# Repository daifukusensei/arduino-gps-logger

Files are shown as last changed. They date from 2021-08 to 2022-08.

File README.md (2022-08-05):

# Project Pluto: Arduino GPS w/ microSD logging and Bluetooth
This is Project Pluto: an Arduino-based battery-powered GPS data-logger with customizable settings and Bluetooth pairing to mobile phone or compatible DSLR.

The finished product is self-contained on a printed PCB in a 3D-printed enclosure, with majority of components plugged into headers to aid in possible future upgrades and enable repurposing of components.

<p align="center">
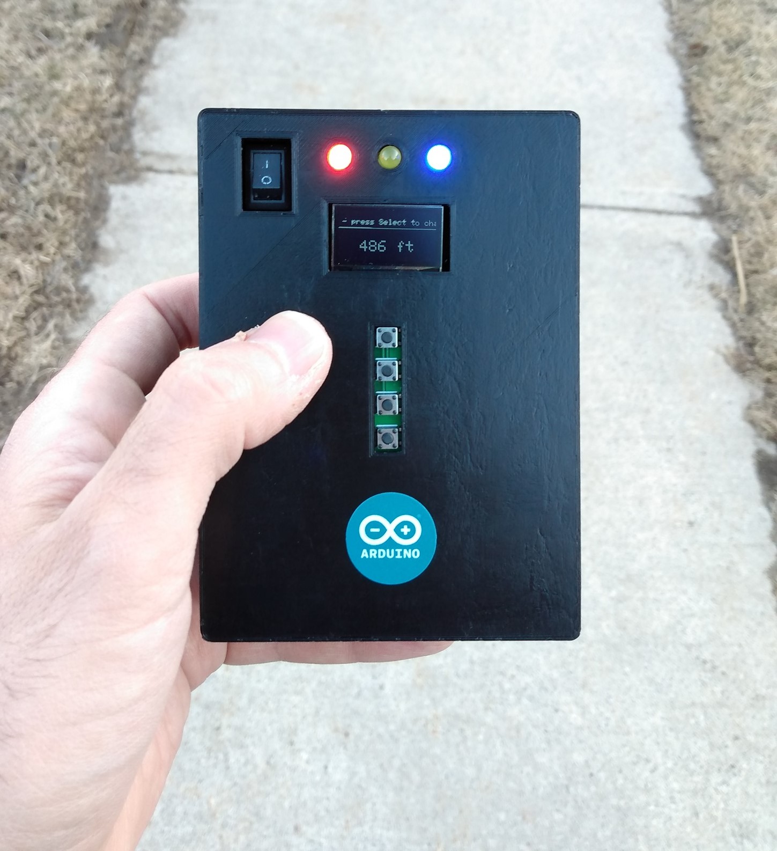
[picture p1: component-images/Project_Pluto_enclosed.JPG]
  
</p>

## Why?
I'm an active travel photographer, and use various hardware & software-based solutions to geo-tag my images on the fly. With no prior knowledge of Arduino development, CAD, electronics or circuit design, I wanted to see if I was able to build a portable geo-tagging solution to meet my own needs. And I did it. Kind of (see [Disclaimer](#Disclaimer)).

On a whim and for no particular reason, I've named it Project Pluto.

## Features
- Display of various parameters in real-time (co-ordinates, date & time, speed, altitude, heading and satellite count), with the ability to change measurement units where applicable (ie. feet or meters)
- Logging of co-ordinates to microSD card
- Bluetooth pairing with mobile phone or NMEA 0183-compatible DSLR (see [Specifications and Requirements](#Specifications-and-Requirements))
- LEDs to indicate satellite and Bluetooth fix, and microSD card activity
- Individual features (logging, Bluetooth, LEDs) may be toggled on or off, with settings retained across power-cycles
- Long-pressing of individual buttons to quickly toggle key settings (logging, Bluetooth or LED state)

## Repository Contents
- [C++ source code](./arduino-gps-logger.ino) for uploading to an Arduino or compatible clone
- [EasyEDA project](./PCB) for modifying the PCB schematic
- [Fritzing circuit diagram](./Fritzing-circuit-diagram.fzz)
- [Gerber file](./PCB) for printing a PCB
- [STL files](./STL) for 3D-printing an enclosure

## Parts List
| Quantity | Description | Note |
| --- | --- | --- |
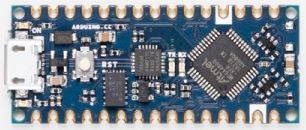
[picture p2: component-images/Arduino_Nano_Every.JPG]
Image of Arduino Nano Every
| 1 | Arduino Nano Every w/ soldered straight male headers | A genuine Arduino Nano Every is required as clones do not use the required ATMega4809 processor<br/> |
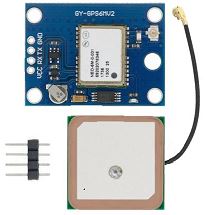
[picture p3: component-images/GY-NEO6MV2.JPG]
Image of GY-NEO6MV2
| 1 | u-blox NEO-6M GPS module w/ external antenna and built-in EEPROM, and soldered straight male header | Part GY-NEO6MV2:<br/> |
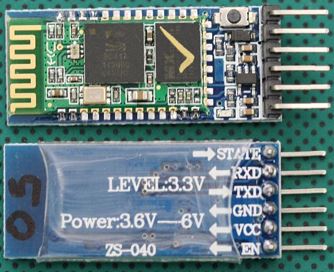
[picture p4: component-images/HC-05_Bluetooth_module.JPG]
Image of HC-05 Bluetooth module
| 1 | HC-05 Bluetooth module on ZS-040 baseboard w/ soldered right-angle male header | Enable and State pins need to be connected for programming<br/> |
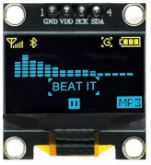
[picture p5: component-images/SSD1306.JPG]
Image of SSD1306 0.96" 128x64 I2C OLED
| 1 | SSD1306 0.96" 128x64 I2C OLED display w/ soldered straight male header | Of the following form-factor:<br/> |
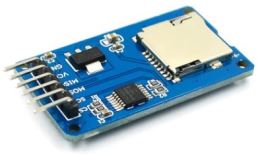
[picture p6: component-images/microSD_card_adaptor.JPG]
Image of SPI microSD card adaptor
| 1 | SPI microSD card adaptor w/ soldered right-angle male header | Of the following form-factor:<br/> |
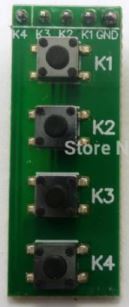
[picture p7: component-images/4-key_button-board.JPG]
Image of 4-key button-board module
| 1 | 4-key button-board module w/ soldered straight male header | |
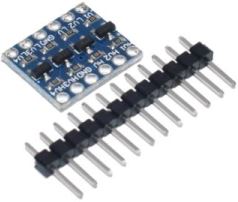
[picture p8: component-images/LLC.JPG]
Image of LLC
| 1 | 4-channel 3.3V/5V bi-directional logic-level-converter (LLC) w/ soldered straight male headers | Of the following form-factor:<br/> |
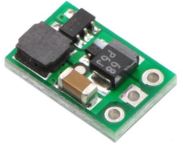
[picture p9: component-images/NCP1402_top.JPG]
Image of NCP1402 top
| 1 | Pololu 5V step-up voltage regulator w/ soldered straight male header | Part NCP1402:<br/>Image of NCP1402 bottom |
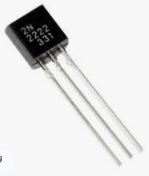
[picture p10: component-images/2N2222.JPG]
Image of 2N2222
| 1 | 2N2222 NPN transistor | For turning on and off the HC-05 Bluetooth module<br/> |
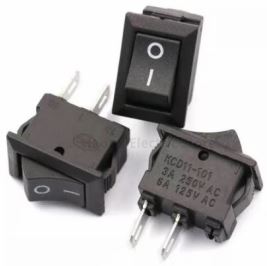
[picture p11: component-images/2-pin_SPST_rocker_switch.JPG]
Image of 2-pin SPST rocker switch
| 1 | 2-pin SPST rocker switch | 15mm\*10mm, in the following form-factor:<br/> |
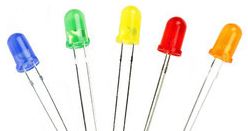
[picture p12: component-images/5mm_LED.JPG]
Image of 5mm LED
| 3 | 5mm LED | Can be a standard 'dome' shape, resulting in slight protusion when in enclosure; or flat-top, which will be flush with enclosure.<br/>Each should ideally be of a different color to represent their distinct use; I use red for satellite fix, yellow for logging, and blue for Bluetooth fix<br/> |
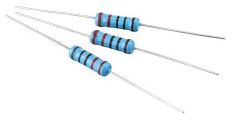
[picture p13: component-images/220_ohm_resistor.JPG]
Image of 220Ω resistor
| 3 | 220Ω resistor |  |
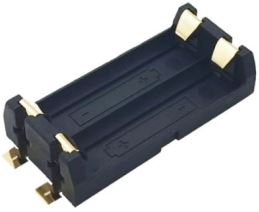
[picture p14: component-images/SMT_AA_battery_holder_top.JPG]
Image of SMT AA battery holder top
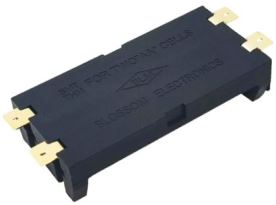
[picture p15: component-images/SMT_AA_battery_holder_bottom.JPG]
Image of SMT AA battery holder bottom
| 1 | SMT AA battery holder | Approximately 59mm\*29mm (from Blossom Electronics, or Keystone part 1022):<br/> |
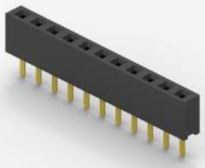
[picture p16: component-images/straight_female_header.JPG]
Image of straight female header
| 1 | 3-pin 2.54mm-pitch straight female header | Source rows of these in bulk, from which the required size can be cut:<br/> | 
| 2 | 15-pin 2.54mm-pitch straight female header | Source rows of these in bulk, from which the required size can be cut:<br/>Image of straight female header |
| 2 | 4-pin 2.54mm-pitch straight female header | Source rows of these in bulk, from which the required size can be cut:<br/>Image of straight female header |
| 2 | 6-pin 2.54mm-pitch right-angle female header | Source rows of these in bulk, from which the required size can be cut:<br/>Image of right-angle female header |
| 2 | 6-pin 2.54mm-pitch straight female header | Source rows of these in bulk, from which the required size can be cut:<br/>Image of straight female header |
| 3 | 2-pin 2.54mm-pitch straight female header | Source rows of these in bulk, from which the required size can be cut:<br/>Image of straight female header |
| 4 | 6mm M2 screw | Used in retaining u-blox NEO-6M GPS module and SSD1306 0.96" 128x64 I2C OLED display on printed PCB.<br/>Source a single 'M2 Male-Female Spacer Standoff Screw Nut' kit that contains all required screw/spacer/standoff parts from this list:<br/>Image of 6mm screw |
| 2 | 8mm M2 screw | Used in retaining 4-key button-board module on printed PCB.<br/>Source a single 'M2 Male-Female Spacer Standoff Screw Nut' kit that contains all required screw/spacer/standoff parts from this list:<br/>Image of 8mm screw |
| 8 | M2 spacer | Used in retaining u-blox NEO-6M GPS module, SSD1306 0.96" 128x64 I2C OLED display, 4-key button-board module and SPI microSD card adaptor on printed PCB.<br/>Source a single 'M2 Male-Female Spacer Standoff Screw Nut' kit that contains all required screw/spacer/standoff parts from this list:<br/>Image of spacer |
| 2 | 6mm M2 double-passthrough standoff | Used in retaining SPI microSD card adaptor on printed PCB.<br/>Source a single 'M2 Male-Female Spacer Standoff Screw Nut' kit that contains all required screw/spacer/standoff parts from this list:<br/>Image of 6mm standoff |
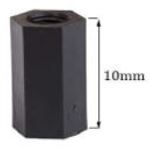
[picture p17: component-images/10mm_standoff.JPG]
Image of 10mm standoff
| 6 | 10mm M2 double-passthrough standoff | Used in retaining u-blox NEO-6M GPS module and SSD1306 0.96" 128x64 I2C OLED display on printed PCB.<br/>Source a single 'M2 Male-Female Spacer Standoff Screw Nut' kit that contains all required screw/spacer/standoff parts from this list:<br/> |
| 11 | 12mm M2 screw | Used in retaining HC-05 Bluetooth module and SPI microSD card adaptor on printed PCB, and to fasten enclosure.<br/>Source a single 'M2 Male-Female Spacer Standoff Screw Nut' kit that contains all required screw/spacer/standoff parts from this list:<br/>Image of 12mm screw |
| 1 | M2 nut | Used in retaining HC-05 Bluetooth module on printed PCB.<br/>Source a single 'M2 Male-Female Spacer Standoff Screw Nut' kit that contains all required screw/spacer/standoff parts from this list:<br/>Image of nut |
| 8 | M2 washer | Used in fastening enclosure, to avoid fracturing.<br/>Source a single 'M2 Male-Female Spacer Standoff Screw Nut' kit that contains all required screw/spacer/standoff parts from this list:<br/>Image of spacer |
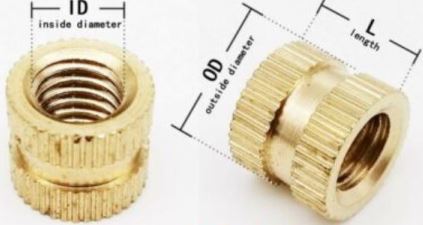
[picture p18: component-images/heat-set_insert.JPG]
Image of heat-set insert
| 8 | 3.5mm\*5mm M2 heat-set insert | Used in fastening enclosure.<br/>Inside diameter of M2 (2mm), outside diameter of 3.5mm, inside length of 5mm:<br/> |
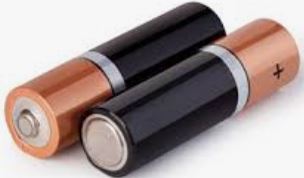
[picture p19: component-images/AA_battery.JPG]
Image of AA battery
| 2 | AA battery |  |

## Libraries and Compile Requirements
Project Pluto uses the following libraries:
- [Adafruit SSD1306](https://github.com/adafruit/Adafruit_SSD1306)
- [EEPROM](https://www.arduino.cc/en/Reference/EEPROM)
- [NeoGPS](https://github.com/SlashDevin/NeoGPS)
- [SdFat](https://github.com/greiman/SdFat)
- [SoftwareSerial](https://www.arduino.cc/en/Reference/softwareSerial)
- [SPI](https://www.arduino.cc/en/reference/SPI)

I had to do the following to compile against the Arduino Nano Every, though these changes may no longer be required:
- NeoGPS: remove the `class Print` forward declarations from the following files:
    - DMS.h
    - NeoTime.h
- SdFat: set `SPI_DRIVER_SELECT` to `1` in **SdFatConfig.h** per [greiman/SdFat-beta#42](https://github.com/greiman/SdFat-beta/issues/42)
- Change `#define F(str) (str)` in **Arduino.h** to `#define F(str) (const __FlashStringHelper*)(str)`

## Build Instructions
<p align="center">
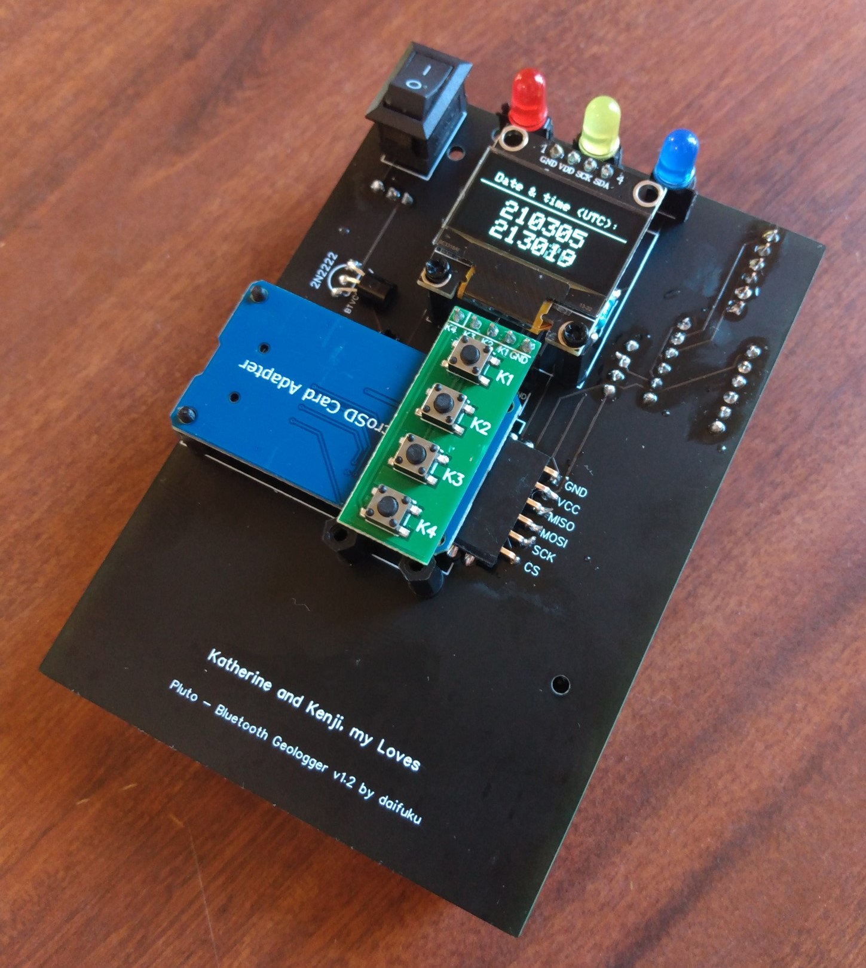
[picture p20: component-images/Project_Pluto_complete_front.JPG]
  
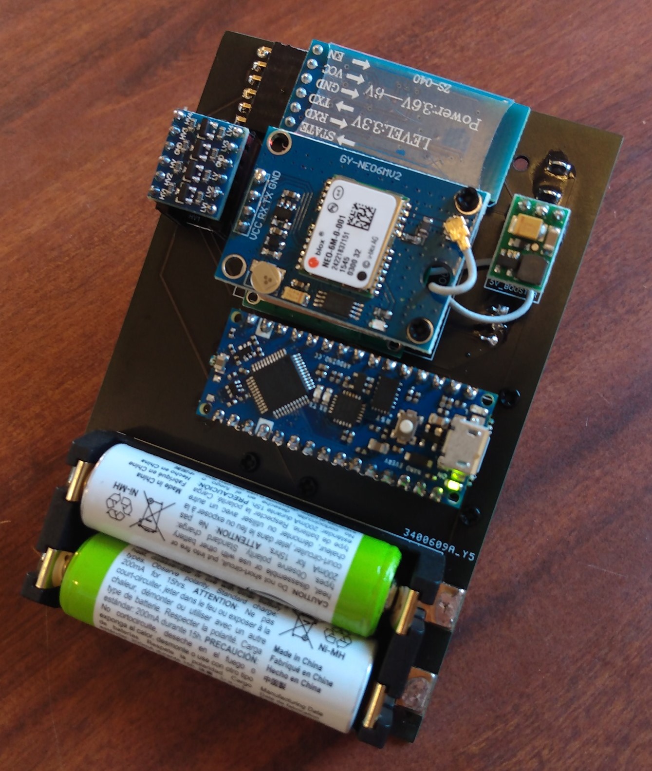
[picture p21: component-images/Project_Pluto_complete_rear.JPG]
  
</p>

Due to the overlapping of the Arduino Nano Every and SPI microSD card adaptor on opposing sides of the PCB, I suggest building in the following sequence:
1. Upload [arduino-gps-logger.ino](./arduino-gps-logger.ino) to Arduino Nano Every
2. Print this repository's STL files; I forget settings used, but note the following:
    - Wall thickness should be adjusted to accommodate heat-set inserts
    - Supports are required only for [Project-Pluto-enclosure-bottom.stl](./STL/Project-Pluto-enclosure-bottom.stl)
    - I've applied gluestick to the printer's bed
3. Insert heat-set inserts to holes on printed [Project-Pluto-enclosure-top.stl](./STL/Project-Pluto-enclosure-top.stl)
4. [Print a PCB](https://jlcpcb.com/) from this repository's Gerber file, with the following settings:
    - 2 layers
    - 1.6mm PCB thickness
5. Solder **220Ω resistors**, **2N2222 NPN transistor** and **2-pin SPST rocker switch** in their respective footprints on the PCB
6. Solder all **straight female headers** from the [Parts List](#Parts-List) to each component's respective footprint on the PCB, except for the microSD card adaptor and HC-05 Bluetooth module
7. Solder **right-angle female headers** to the footprints of the **HC-05 Bluetooth module** and **microSD card adaptor**, slightly tilting back the latter to clear the Arduino Nano Every female header's solder joints
8. Solder **SMT AA battery holder**, ensuring correct orientation of terminals according to footprint on PCB
9. Trim legs of each LED so base rests flush with female headers
10. Plug-in and screw-down (where required) remaining components:
    - HC-05 Bluetooth module
    - u-blox NEO-6M GPS module
    - LLC
    - Pololu 5V step-up voltage regulator
    - Arduino Nano Every
    - LEDs
    - SSD1306 0.96" 128x64 I2C OLED display
    - SPI microSD card adaptor
    - 4-key button-board module
11. Recess the completed unit into the front half of the enclosure, being careful to ensure the LEDs slip properly into their respective cavities
12. Insert AA batteries
13. Screw-down enclosure with 12mm M2 screws (and washers, to avoid fracturing the enclosure)

## Operating Instructions
### Specifications and Requirements
- u-blox NEO-6M GPS and HC-05 Bluetooth modules operate at 4800 baud, for Nikon DLSR-compatibility
- Pairs with any Bluetooth Serial Port Profile (SPP) NMEA 0183-compatible device with PIN/passkey 0000
- microSD card required for logging and waypoint-marking
- When enabled, logging of co-ordinates to microSD card at 2-second intervals
- Battery life is poor; expect 2 to 4 hours

### Startup Sequence
1. Any user-changed settings are restored from EEPROM
2. If **Waypoint-Marker** button is held, reset baud rate of HC-05 Bluetooth module to 4800 (required for Nikon DSLR pairing using Bluetooth dongle)
3. Initialize access to microSD card if one's inserted; else disable logging
4. Set baud rate of u-blox NEO-6M GPS module to 4800 (required for Nikon DSLR pairing using Bluetooth dongle)
5. Set compatibility mode on u-blox NEO-6M GPS module and co-ordinate-system to 4-decimal places (required for Nikon DSLR pairing using Bluetooth dongle)
6. Up-and-running

### Display and Navigation
- The **main** interface is comprised of individual screens that display different information:
    - Date & Time (UTC)
    - Speed
    - Heading
    - Altitude
    - Satellite count
- The **Settings** screen displays the following user-configurable options:
    - Logging: ON or OFF; remains OFF if microSD card not inserted at boot 
    - Bluetooth: ON or OFF
    - (Screen) Timeout: 5-30 seconds
    - LEDs: ON or OFF
    - Reset to defaults: Logging and Bluetooth OFF; Timeout of 5 seconds; LEDs ON
    - Done: Write settings to EEPROM for recalling across power-cycles
- See the [Button Functions](#Button-Functions) table regarding how to navigate the interface

### Button Functions
| Button | Short-Press | Long-Press (3-seconds) |
| --- | --- | --- |
| **Select** (**K1** on button-board; **D5** on PCB) | - Change measurement units where applicable<br/>- Toggle or increment settings<br/>- Highlight on-screen elements requiring confirmation | Toggle logging state on and off and write to EEPROM for recalling across power-cycles |
| **Next** (**K2** on button-board; **D6** on PCB) | - Cycle through screens<br/>- Confirm highlighted selection | Toggle Bluetooth state on and off and write to EEPROM for recalling across power-cycles |
| **Waypoint-Marker** (**K3** on button-board; **D7** on PCB) | N/A | **During normal use:**<br/>- Record current co-ordinates in file on microSD card, regardless of logging state<br/>- Requires a satellite-fix and microSD card inserted at boot<br/><br/>**During startup:**<br/>- Reset baud rate of HC-05 Bluetooth module to 4800 (required for Nikon DSLR pairing using Bluetooth dongle) |
| **LED State** (**K4** on button-board; **D8** on PCB) | N/A | Toggle state of all LEDs on and off and write to EEPROM for recalling across power-cycles |

### LED Behaviour
- **GPS** (left-most LED)
    - Blink: No satellite-fix
    - On: Satellite-fix
- **Logging** (middle LED)
    - Blink: microSD card activity
    - On: microSD card not inserted at boot or error writing to card
- **Bluetooth** (right-most LED)
    - Blink: Searching
    - On: Paired
    - Off: Bluetooth is disabled
- Long-pressing a button to toggle settings on and off results in the respective LED being lit for 2-seconds to visually indicate state change

### microSD Card Behaviour
- When logging is on:
  1. File **yymmdd_log_nn.txt** is created in the root of the microSD card with a header row each time logging state is changed to **ON** and a date & time is acquired from the GPS (where **yymmdd** equals current UTC date, and **nn** equals incrementing number beginning with 00)
  2. Given a satellite-fix, the following comma-delimited fields are appended to the file at 2-second intervals
     - Latitude
     - Longitude
     - Speed (km/h)
     - Heading (degrees)
     - Altitude (floating-point meters)
     - Date and Time (UTC)
- Waypoint-markers are appended to file **waypoints.txt** in the same format as above, regardless of logging state

## Disclaimer
**Build and use at your own risk.** I am not an electrical engineer, nor a working C++ developer; this is a passion-project constructed in between diaper changes and one-too-many beers, and is likely replent with bugs. That said, it functions as intended, and has yet to blow up.

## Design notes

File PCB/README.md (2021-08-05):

# Project Pluto: EasyEDA Project and Gerber File

<p align="center">
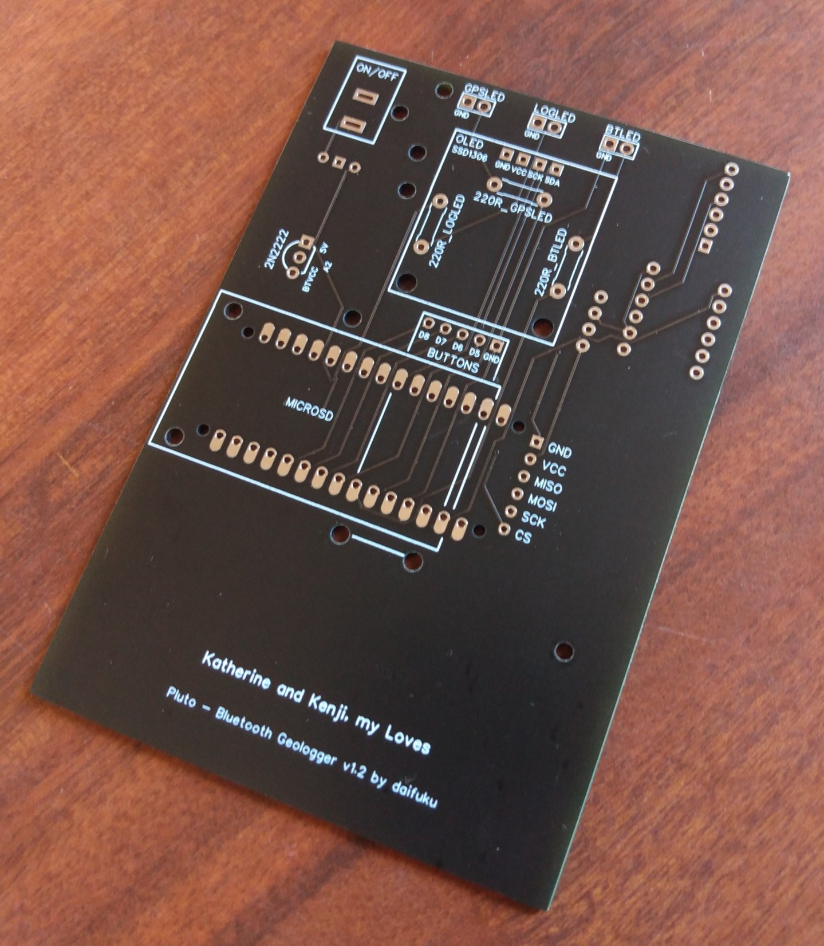
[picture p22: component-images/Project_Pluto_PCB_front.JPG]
  
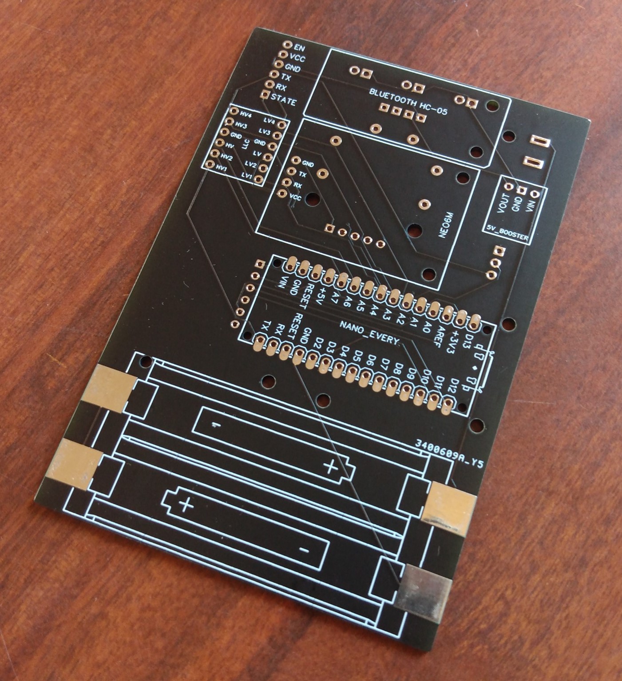
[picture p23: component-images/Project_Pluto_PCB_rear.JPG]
  
</p>

- **Project-Pluto-EasyEDA-project.zip**
    - Zip file containing the schematic and PCB as an editable EasyEDA project
    - Unzip and manually add contents to your EasyEDA project directory

- **Project-Pluto-Gerber.zip**
    - A completed PCB, ready for [printing](https://jlcpcb.com/)
    - Print with the following settings:
      - 2 layers
      - 1.6mm PCB thickness

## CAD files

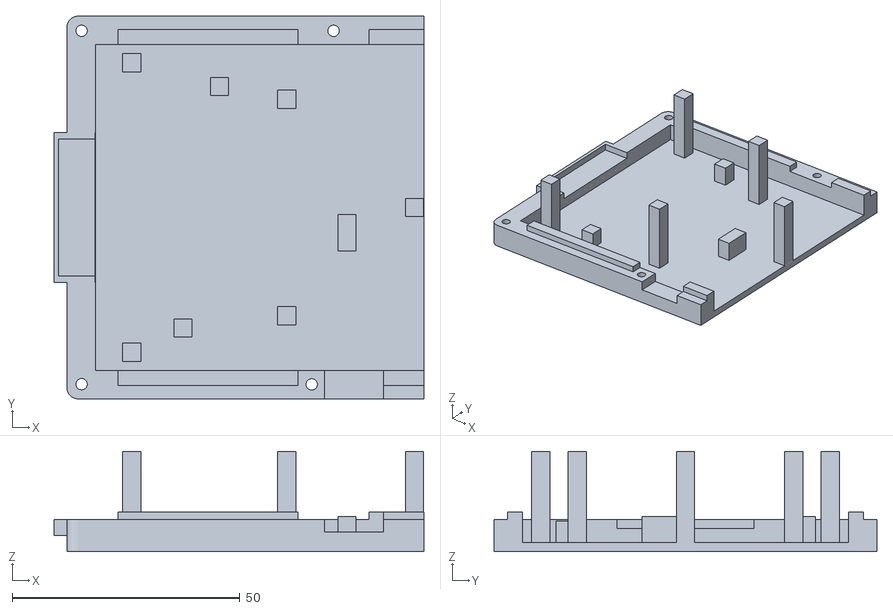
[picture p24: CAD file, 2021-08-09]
STL/Project-Pluto-enclosure-bottom.stl
81.1 x 84.0 x 22.0

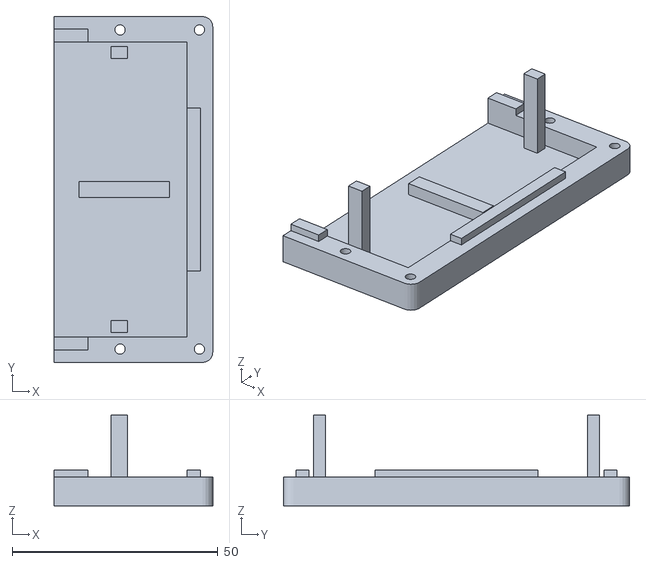
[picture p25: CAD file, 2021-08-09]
STL/Project-Pluto-enclosure-battery-cover.stl
38.5 x 84.0 x 22.0

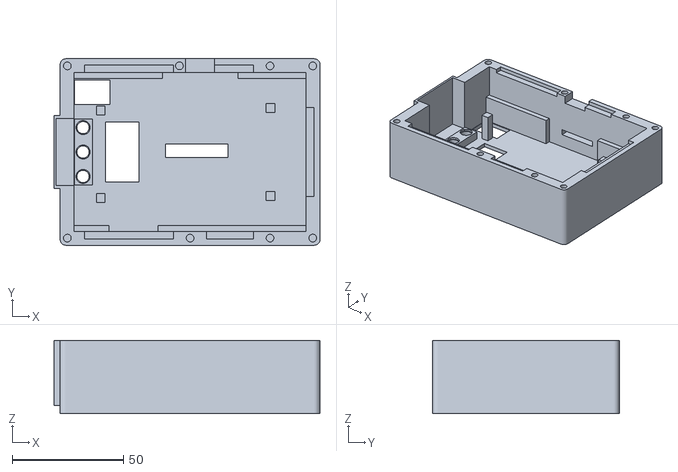
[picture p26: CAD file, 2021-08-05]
STL/Project-Pluto-enclosure-top.stl
119.8 x 84.0 x 33.0

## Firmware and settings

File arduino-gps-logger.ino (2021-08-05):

// GPS code from https://randomnerdtutorials.com/guide-to-neo-6m-gps-module-with-arduino/
// LED blinking code from https://learn.adafruit.com/multi-tasking-the-arduino-part-1/using-millis-for-timing
// EEPROM code from https://www.arduino.cc/en/Tutorial/EEPROMWrite, https://www.arduino.cc/en/Reference/EEPROMRead
// Software Serial code from https://www.arduino.cc/en/tutorial/SoftwareSerialExample

#include <Adafruit_SSD1306.h>
#include <EEPROM.h>
#include <NMEAGPS.h>
#include <SdFat.h>
#include <SoftwareSerial.h>
#include <SPI.h>

#define SCREEN_WIDTH 128 // OLED display width, in pixels
#define SCREEN_HEIGHT 64 // OLED display height, in pixels
#define GPSPORT Serial1 // serial port of the connected GPS

#define OLED_RESET -1 //4 // reset pin # (or -1 if sharing Arduino reset pin)
// Nano Every pins:
#define BTENPIN 17 // the number of the bluetooth HC-05 module's EN pin, used for initiating AT mode to re-configure the device
#define BTRXPIN 21 // the number of the bluetooth HC-05 module's RX pin, used for receiving AT commands issued via serial communication
#define BTVCCPIN 16 // the number of the 2N2222 transistor's base pin, used to power on/off the bluetooth HC-05 module
#define BTSTATEPIN 15 // the number of the bluetooth HC-05 module's state pin, used for controlling the bluetooth state LED
#define BTNLED 8 // the number of the LED state-toggle button's pin
#define BTNNEXT 6 // the number of the next page button's pin (used for switching screen pages and toggling bluetooth state)
#define BTNSELECT 5 // the number of the select button's pin (used for changing settings and toggling logging state)
#define BTNMARKER 7 // the number of the waypoint-marker button's pin (used for marking a waypoint)
#define LEDBLUETOOTH 4 // the number of the bluetooth LED
#define LEDGPS 3 // the number of the GPS-fix LED
#define LEDLOG 2 // the number of the logging LED (indicates writes to microSD card)
// Mega2560 pins:
/*#define BTENPIN 23 // the number of the bluetooth HC-05 module's EN pin, used for initiating AT mode to re-configure the device
#define BTRXPIN 22 // the number of the bluetooth HC-05 module's RX pin, used for receiving AT commands issued via serial communication
#define BTVCCPIN 43 // the number of the 2N2222 transistor's base pin, used to power on/off the bluetooth HC-05 module
#define BTSTATEPIN 25 // the number of the bluetooth HC-05 module's state pin, used for controlling the bluetooth state LED
#define BTNNEXT 8 // the number of the next page button's pin (used for switching screen pages)
#define BTNSELECT 7 // the number of the select button's pin (used for changing settings)
#define BTNMARKER 9 // the number of the waypoint-marker button's pin (used for marking a waypoint)
#define LEDBLUETOOTH 6 // the number of the bluetooth LED
#define LEDGPS 5 // the number of the GPS-fix LED
#define LEDLOG 4 // the number of the logging LED (indicates writes to microSD card)*/
Adafruit_SSD1306 display(SCREEN_WIDTH, SCREEN_HEIGHT, &Wire, OLED_RESET);

SoftwareSerial BTSERIAL(20, BTRXPIN); // RX, TX on Arduino board

// define button struct
typedef struct Btn {
  Btn(byte pin); // the physical number of the button's pin
  byte pin; // the physical number of the button's pin
  byte currState = 0; // current state of button press (LOW or HIGH)
  byte lastState = 0; // prior state of button press for comparison during program execution
  boolean ignore = false; // used to help manage button presses
  boolean longPress = false; // indicates when a button was long-pressed, intended for changing settings at next display redraw
  boolean shortPress = false; // indicates when a button was short-pressed, intended for changing settings at next display redraw
  unsigned long millisDown = 0; // milliseconds since a button has first been held
  unsigned long millisUp = 0; // milliseconds since a button has been released
  void checkState(); // method for checking the state of each button
};

// define led class
typedef struct Led {
  Led(byte pin); // the physical number of the LED's pin
  byte pin; // the physical number of the LED's pin
  boolean turnOff = false; // flag to set LED state to LOW (off) on next pass of checkLeds() function
  unsigned long millisLedOnStart = 0; // milliseconds since last time LED was first turned on
  byte millisLedOnMax; // max milliseconds of on-time for LED when blinking
  short int millisLedOffMax; // max milliseconds of off-time for LED when blinking
  void blink(); // method for blinking LED at defined intervals with each pass of checkLeds() function
  boolean longBlink = false; // flag to indicate that LED should remain on for an extended period of time at next blink interval
  void turnOn(); // method for immediately setting LED state to HIGH (on)
};

Btn btnLedState(BTNLED); // create a Btn object for the LED state-toggle button
Btn btnNext(BTNNEXT); // create a Btn object for the next page button (used for switching screen pages)
Btn btnSelect(BTNSELECT); // create a Btn object for the select button (used for changing settings)
Btn btnMarker(BTNMARKER); // create a Btn object for the waypoint-marker button (used for marking a waypoint)
Led ledBluetooth(LEDBLUETOOTH); // create an Led object for the bluetooth LED
Led ledGps(LEDGPS); // create an Led object for the GPS-fix LED
Led ledLog(LEDLOG); // create an Led object for the logging LED (indicates writes to microSD card)

NMEAGPS gps; // GPS object
gps_fix fix; // GPS fix structure
SdFat SD; // microSD card object
File logfile; // file to log to on microSD card

// define constants
// Nano Every pin:
const byte sdCSPin = 14; // the number of the microSD card adapter CS pin
// Mega2560 pin:
//const byte sdCSPin = 53; // the number of the microSD card adapter CS pin
const unsigned short int baud = 4800; // target baud rate of the bluetooth and GPS modules
const short int millisDispRefreshOffMax = 2000; // max milliseconds display refresh/inputs are blocked, for display of system messages
const short int millisBtnLongPressMax = 2000; // max milliseconds before a button long-press is detected
const short int millisLoggingInterval = 2000; // interval between writes to microSD card
const short int millisTextScrollPause = 2000; // max milliseconds text is statically displayed before scrolling
const byte mainPageCount = 7; // number of main screen pages
const byte subPageCount = 6; // number of sub (settings) screen pages
const byte subPageSetTimeoutMin = 5; // minimum allowable value for display timeout
const byte subPageSetTimeoutMax = 30; // maximum allowable value for display timeout

// define global variables
boolean dispOn = false; // used to indicate if the display is currently on
boolean dispRefresh = true; // used to toggle display refreshing & interrupts to allow for display of system messages
boolean sdCardReady = false; // used to indicate if microSD card is ready
boolean sdLogReady = false; // used to indicate if a logfile on microSD has been created and is available for writing
unsigned long millisDispOnStart = 0; // milliseconds since display has been turned on
unsigned long millisDispRefreshOffStart = 0; // milliseconds since display refresh/inputs were first blocked
unsigned long millisLoggingStart = 0; // milliseconds since last time access to the microSD card was initiated
unsigned long millisTextScrollStart = 0; // milliseconds since text scrolling timer started
boolean mainScreenActive = true; // used to indicate if the main screen or sub (settings) screen is active
byte mainPageValue = 0; // used to cycle through available main screen pages
byte subPageValue = 0; // used to cycle through available sub (settings) screen pages
boolean cursorEnterSettings = false; // used to indicate if "Enter" text is selected on main screen settings page
boolean inMeikeHousing = true; // indicates if display is housed in a Meike MK-RC10N flash trigger, with less real estate
short int currX = display.width(); // starting X-coordinate for when text scrolling is needed
char logfileName[] = "yymmdd_log_##.txt"; // dynamic track logging filename on microSD card (based on unique date & number-sequence)
char str1[11]; // maximum number of characters at textsize=2 that can fit on one line of the display, +1 for null terminator
char str2[11];

// main screen page display toggle parameters
byte mainPageSetAltitudeVal = 0; // display altitude in feet, meters, kilometers or miles (default feet)
boolean mainPageSetSpeedKm = true; // display speed in either km/h or mph (default km/h)

// settings screen page parameters
boolean subPageSetBluetoothOn = false; // bluetooth is either OFF or ON (default OFF)
boolean subPageSetLedOn = true; // LEDs are either ON or OFF (default ON)
boolean subPageSetLoggingOn = false; // logging is either OFF or ON (default OFF)
long subPageSetTimeoutVal = 0; // 5-30
boolean subPageSetDefault = false; // used to indicate if next button was pressed on "Defaults" text in sub (settings) screen
boolean subPageSetDone = false; // used to indicate if next button was pressed on "Done" text in sub (settings) screen

void setup() {
  if (! display.begin(SSD1306_SWITCHCAPVCC, 0x3C)) { // address 0x3D for 128x64
    for (;;); // failed to initialize OLED display so don't proceed; loop forever
  }

  //setDefaults();  // erase EEPROM and set to defaults
  //writeEeprom();
 
  // read EEPROM values into memory
  readEeprom();

  // intialize the LEDs
  ledBluetooth.millisLedOnMax = 100;
  ledBluetooth.millisLedOffMax = 1000;
  ledGps.millisLedOnMax = 100;
  ledGps.millisLedOffMax = 1000;
  ledLog.millisLedOnMax = 100;

  // initialize the display
  display.ssd1306_command(SSD1306_DISPLAYOFF);
  display.setTextColor(SSD1306_WHITE);
  millisDispOnStart = millis(); // start the display on/off state timer

  pinMode(BTENPIN, OUTPUT);
  digitalWrite(BTENPIN, LOW); // bluetooth HC-05 module's EN pin is only used when re-configuring the device, and is thus set to LOW
  pinMode(BTVCCPIN, OUTPUT);
  digitalWrite(BTVCCPIN, LOW); // start with bluetooth HC-05 module off unless user settings (read later from EEPROM) indicate otherwise
  pinMode(BTRXPIN, INPUT); // set Arduino's TX pin (bluetooth HC-05 module's RX pin) to input mode so as to not interfere with GPS
                           // NMEA sentences being sent to the HC-05 module's same RX pin and the same 'line' to Arduino's serial RX--
                           // perhaps one day I'll learn enough to figure out the issue and why input mode works

  // reset the bluetooth HC-05 module's baud rate to our target baud rate should it have been forgotten by holding the
  // waypoint-marker button when powering on-- may require a few attempts
  if (digitalRead(btnMarker.pin) == LOW) {
    ledBluetooth.turnOn(); // immediately turn on the bluetooth LED to indicate attempted setting of baud rate
    setBluetoothBaudRate(baud);
  }

  // initialize the microSD card
  sdInit();

  GPSPORT.begin(9600); // open serial connection with GPS at default baud rate of 9600
  
  setGpsBaudRate(baud); // set the GPS baud rate to 4800 with each startup
  byte compatMode[] = { 0xB5, 0x62, 0x06, 0x17, 0x04, 0x00, 0x00, 0x23, 0x00, 0x03, 0x47, 0x55, 0xE3, 0xC6 };
  sendUBX(compatMode, sizeof(compatMode) / sizeof(byte)); // set the GPS compat flag via a u-blox UBX-CFG-NMEA command to enable
                 // compatibility mode and present co-ordinates in 4 decimal places rather than 5, required for Nikon cameras
}

void loop() {
  checkDisplay(); // manage display refresh & on/off state

  // display specific main screen page
  if (dispRefresh) { // only allow for changes if dispRefresh = true, to allow for display of system messages and user actions
    if (dispOn) { // only refresh the display if it's currently on
      if (btnNext.shortPress) { // next button was short-pressed, so change screen page
        changeScreenPage();
      } else {
        if (mainScreenActive) {
          drawMainScreenPage(); // refresh the selected main screen page if it's active
        } else {
          drawSubScreenPage(); // refresh the selected sub (settings) screen page if it's active
        }
      }
    }
  }

  checkBtns(); // check state of buttons
  checkLeds(); // take action on LEDs (blink, turn off, etc.)
  checkSerialData(); // check incoming serial data and pass to gps object
  checkBluetooth(); // take actions against bluetooth HC-05 module
  checkLogger(); // take logging actions
}

void checkDisplay() {
  // re-enable display refresh if it's been disabled longer than millisDispRefreshOffMax
  if (! dispRefresh) {
    if (millis() - millisDispRefreshOffStart >= (millisDispRefreshOffMax)) {
      dispRefresh = true;
    }
  }

  // turn off display if it's not already off, and if it's been on longer than the defined timeout
  if ((millis() - millisDispOnStart >= (subPageSetTimeoutVal * 1000)) && (dispOn == true)) {
    display.ssd1306_command(SSD1306_DISPLAYOFF);
    dispOn = false;
  }
}

void checkBtns() {
  btnLedState.checkState();
  btnNext.checkState();
  btnSelect.checkState();
  btnMarker.checkState();

  // only take action on long-presses if we're on the main screen, to avoid confusingly overwriting
  // user settings on the settings screen that may not have been intentionally changed & saved yet
  if (mainScreenActive) {
    // toggle LED state
    if (btnLedState.longPress) { // the LED state-toggle button was long-pressed, so take action regardless of display being on/off
      millisDispOnStart = millis();
      display.ssd1306_command(SSD1306_DISPLAYON); // turn on display
      dispOn = true; // indicate that display is on
      display.clearDisplay();
      if (subPageSetLedOn) {
        drawBodyText("LEDs", "OFF!"); // LEDs were enabled, so disable them
      } else {
        drawBodyText("LEDs", "ON!"); // LEDs were disabled, so enable them
      }
      subPageSetLedOn = ! subPageSetLedOn; // toggle LED state and write to EEPROM
      writeEeprom();
      display.display();
      dispRefresh = false; //prevent display refresh and button input to allow display of system messages and user actions
      millisDispRefreshOffStart = millis();
    }
    
    // add a waypoint-marker
    if (btnMarker.longPress) { // the waypoint-marker button was long-pressed, so take action regardless of display being on/off
      millisDispOnStart = millis();
      display.ssd1306_command(SSD1306_DISPLAYON); // turn on display
      dispOn = true; // indicate that display is on
      display.clearDisplay();
      if (sdCardReady) { // attempt to mark a waypoint only if microSD card is accessible
        if (fix.valid.location) {
          ledLog.longBlink = true; // indicate that logging LED should remain on for a brief period of time to visually indicate a
                                   // waypoint was written to file
          sdWriteMarker(); // write a waypoint to file
          drawBodyText("Marked", "waypoint!"); // mark a waypoint only if there's valid GPS co-ordinates  
        } else {
          drawBodyText("No", "position!"); // no valid GPS co-ordinates available in order to mark a waypoint  
        }
      } else {
        drawBodyText("Card", "error!"); // microSD card failed to initialize earlier, so display an error
      }
      display.display();
      dispRefresh = false; //prevent display refresh and button input to allow display of system messages and user actions
      millisDispRefreshOffStart = millis();
    }
  
    // toggle bluetooth state
    if (btnNext.longPress) { // the next button was long-pressed, so take action regardless of display being on/off
      millisDispOnStart = millis();
      display.ssd1306_command(SSD1306_DISPLAYON); // turn on display
      dispOn = true; // indicate that display is on
      display.clearDisplay();
      if (subPageSetBluetoothOn) {
        drawBodyText("Bluetooth", "OFF!"); // bluetooth was enabled, so disable it
      } else {
        drawBodyText("Bluetooth", "ON!"); // bluetooth was disabled, so enable it
      }
      ledBluetooth.longBlink = true; // indicate that bluetooth LED should remain on for a brief period of time to visually indicate
                                     // change of state
      subPageSetBluetoothOn = ! subPageSetBluetoothOn; // toggle bluetooth state and write to EEPROM
      writeEeprom();
      display.display();
      dispRefresh = false; //prevent display refresh and button input to allow display of system messages and user actions
      millisDispRefreshOffStart = millis();
    }
  
    // toggle logging state
    if (btnSelect.longPress) { // the select button was long-pressed, so take action regardless of display being on/off
      millisDispOnStart = millis();
      display.ssd1306_command(SSD1306_DISPLAYON); // turn on display
      dispOn = true; // indicate that display is on
      display.clearDisplay();
      if (sdCardReady) { // attempt to change logging state only if microSD card is accessible
        if (subPageSetLoggingOn) {
          drawBodyText("Logging", "OFF!"); // logging was enabled, so disable it
        } else {
          drawBodyText("Logging", "ON!"); // logging was disabled and microSD card was successfully initialized earlier, so enable logging
        }
        ledLog.longBlink = true; // indicate that logging LED should remain on for a brief period of time to visually indicate change of
                                 // state
        subPageSetLoggingOn = ! subPageSetLoggingOn; // toggle logging state and write to EEPROM
        writeEeprom();
      } else {
        drawBodyText("Card", "error!"); // microSD card failed to initialize earlier, so display an error
      }
      display.display();
      dispRefresh = false; //prevent display refresh and button input to allow display of system messages and user actions
      millisDispRefreshOffStart = millis();
    }
  }
}

void Btn::checkState() {
  // reset button states so as to not continually change settings/screen pages when redrawing with each loop if button is held too long
  longPress = false;
  shortPress = false;

  currState = digitalRead(pin); // get current state of button to determine if it's been pressed
  if (currState == LOW && dispRefresh) { // button is currently DOWN (pressed/held); reset millisDown timer only if
                                         // dispRefresh = true to prevent longPress action of another button from running
                                         // immediately first long-press is complete
    millisDown = millis();
    if (((millisDown - millisUp) >= millisBtnLongPressMax) && (! ignore)) { // take action on long-presses
      longPress = true; // indicate that the button was long-pressed
      ignore = true; // indicate that the button is still held to avoid acting on another long-press with each loop
    }
    // take action on short-presses- this is differentiated from long-presses by the button needing to be in a released state
    // (HIGH) && the current released state differing from a last recorded state of LOW (to avoid the released state being
    // acted on with each loop) && the button not just having been immediately released following an intended long-press
    // (to prevent the short-press action from unintentionally occurring immediatley after a long-press action):
  } else if ((currState == HIGH) && (currState != lastState) && (! ignore)) {
    millisDispOnStart = millis();
    display.ssd1306_command(SSD1306_DISPLAYON); // turn on display
    if (dispOn) { // only do something if display is already on
      shortPress = true;
    } else { // display was off, so first turn it on upon press of button before permitting further action from button
      dispOn = true; // display is on following a recent button press, so permit button actions with subsequent presses
    }
  } else {
    millisUp = millis();
    ignore = false;
  }
    
  lastState = currState; // save state of button press for comparison with each loop
}
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

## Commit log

2021-08-09 Corrected STL file requiring support
2021-08-09 Added support columns for unfastened components
    Added support columns for unfastened components to ensure they do not dislodge during regular use:
    - AA batteries
    - Arduino Nano Every
    - LLC
    - Pololu 5V step-up voltage regulator
    [Project-Pluto-enclosure-battery-cover.stl, Project-Pluto-enclosure-bottom.stl]
2022-07-24 Renamed sketch
    -renamed to arduino-gps-logger.ino
